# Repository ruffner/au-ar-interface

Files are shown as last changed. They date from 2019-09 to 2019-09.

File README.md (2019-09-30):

# au-ar-interface
machine vision and hdmi interface for alchitry labs au artix 7 fpga

## layer stackup
I use pcbway and this is the layer configuration from them that this board is based on. 
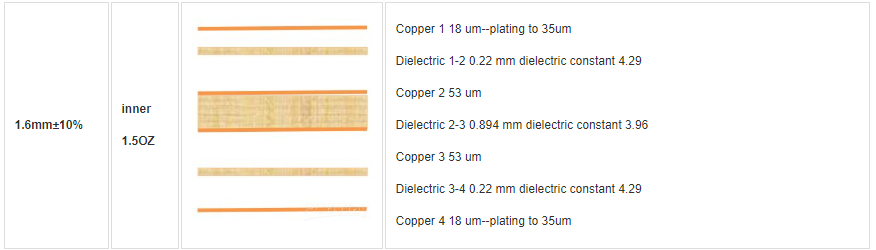
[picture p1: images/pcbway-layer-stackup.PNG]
pcbway 1.6mm 4 layer 1.5oz inner stackup Layer Stackup


## hdmi impedance calcluation and design considerations
Saturn PCB Toolkit was used to calculate the necessary trace widths and spacing to achieve the 100 ohm differential impedance target of the HDMI specification.
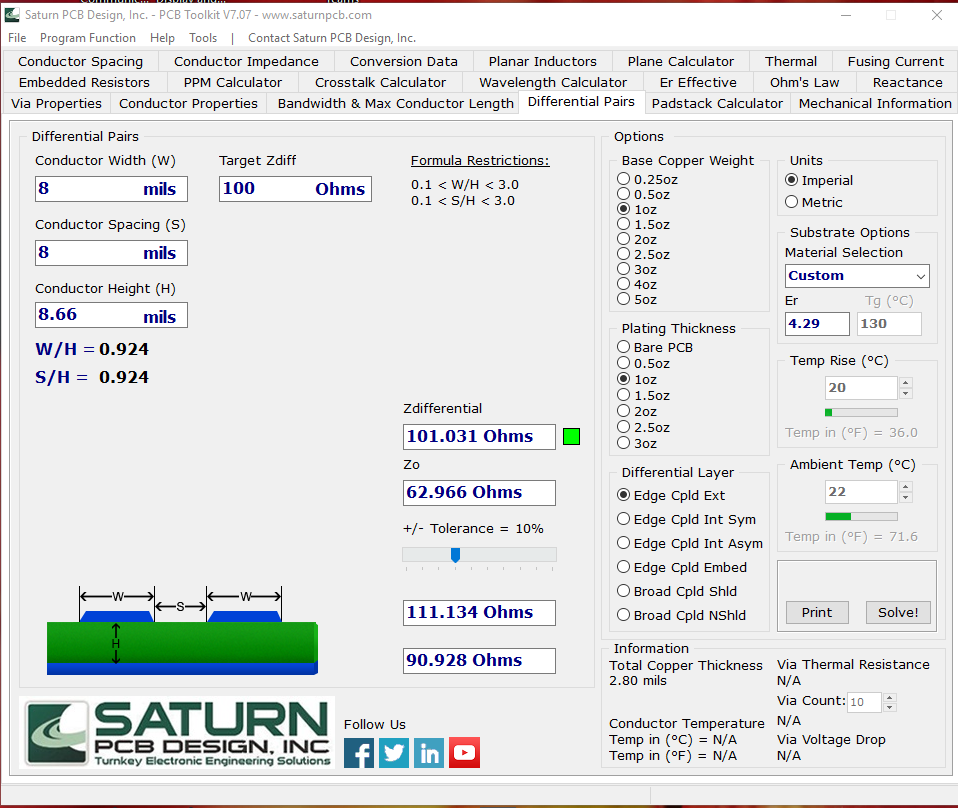
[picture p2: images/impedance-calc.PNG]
pcbway 1.6mm 4 layer 1.5oz inner stackup Impedance and trace calculations


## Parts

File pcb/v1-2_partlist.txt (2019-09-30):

Partlist

Exported from au-ar.sch at 9/30/2019 1:22 PM

EAGLE Version 9.5.1 Copyright (c) 1988-2019 Autodesk, Inc.

Assembly variant: 

Part        Value              Device             Package                Library            Sheet

1           LINE_1             TPTP16R            TP16R                  testpad            4
2           LINE_2             TPTP16R            TP16R                  testpad            4
3           LINE_3             TPTP16R            TP16R                  testpad            4
4           LINE_1             TPTP16R            TP16R                  testpad            4
B1          ALCHITRY_ELEMENTNT ALCHITRY_ELEMENTNT ELEMENT_NO_TOP         alchitry_elements  1
C1          0.1uF              C-USC0603          C0603                  rcl                6
C2          0.1uF              C-USC0603          C0603                  rcl                3
C3          0.1uF              C-USC0603          C0603                  rcl                3
C4          0.1uF              C-USC0603          C0603                  rcl                3
C5          0.1uF              C-USC0603          C0603                  rcl                3
C9          0.1uF              C-USC0603          C0603                  rcl                2
C10         0.1uF              C-USC0603          C0603                  rcl                2
C11         0.1uF              C-USC0603          C0603                  rcl                2
C12         0.1uF              C-USC0603          C0603                  rcl                2
CAMERA1     S6B-PH-K-S(LF)(SN) S6B-PH-K-S(LF)(SN) JST_S6B-PH-K-S(LF)(SN) S6B-PH-K-S_LF__SN_ 4
CAMERA2     S6B-PH-K-S(LF)(SN) S6B-PH-K-S(LF)(SN) JST_S6B-PH-K-S(LF)(SN) S6B-PH-K-S_LF__SN_ 4
FLASH       0532610571         0532610571         PICOBLADE53261-0571    volks73-Molex      5
HDMI_IN/OUT 10029449-001RLF    10029449-001RLF    FCI_10029449-001RLF    10029449-001RLF    2
HDMI_OUT    10029449-001RLF    10029449-001RLF    FCI_10029449-001RLF    10029449-001RLF    2
LINE_1_1    TPTP16R            TPTP16R            TP16R                  testpad            4
LINE_1_2    TPTP16R            TPTP16R            TP16R                  testpad            4
LINE_1_3    TPTP16R            TPTP16R            TP16R                  testpad            4
LINE_1_4    TPTP16R            TPTP16R            TP16R                  testpad            4
R1          DNP                R-US_R0603         R0603                  rcl                4
R2          DNP                R-US_R0603         R0603                  rcl                4
R3          DNP                R-US_R0603         R0603                  rcl                4
R4          DNP                R-US_R0603         R0603                  rcl                4
R5          47k                R-US_R0603         R0603                  rcl                5
R6          3k                 R-US_R0603         R0603                  rcl                6
R7          DNP                R-US_R0603         R0603                  rcl                4
R8          DNP                R-US_R0603         R0603                  rcl                4
R9          DNP                R-US_R0603         R0603                  rcl                4
R10         DNP                R-US_R0603         R0603                  rcl                4
R11         DNP                R-US_R0603         R0603                  rcl                4
R12         DNP                R-US_R0603         R0603                  rcl                4
R13         DNP                R-US_R0603         R0603                  rcl                4
R14         DNP                R-US_R0603         R0603                  rcl                4
R15         DNP                R-US_R0603         R0603                  rcl                4
R16         DNP                R-US_R0603         R0603                  rcl                4
R17         DNP                R-US_R0603         R0603                  rcl                4
R18         DNP                R-US_R0603         R0603                  rcl                4
R19         DNP                R-US_R0603         R0603                  rcl                4
R20         DNP                R-US_R0603         R0603                  rcl                4
R21         DNP                R-US_R0603         R0603                  rcl                4
R22         DNP                R-US_R0603         R0603                  rcl                4
R23         DNP                R-US_R0603         R0603                  rcl                4
R24         DNP                R-US_R0603         R0603                  rcl                4
R25         DNP                R-US_R0603         R0603                  rcl                4
R26         DNP                R-US_R0603         R0603                  rcl                4
R27         3k                 R-US_R0603         R0603                  rcl                6
R28         2k                 R-US_R0603         R0603                  rcl                2
R29         10k                R-US_R0603         R0603                  rcl                2
R30         10k                R-US_R0603         R0603                  rcl                2
SI514       SI514              SI514              XTAL-6PIN              lupa300-components 6
SJ1                            SJ                 SJ                     jumper             2
TP_GND      TPTP16R            TPTP16R            TP16R                  testpad            4
U$1         W25Q80DVSNIG       W25Q80DVSNIG       SOIC8                  TDP12S521          5
U1          TPD12S016PWR       TPD12S016PWR       PW24                   lupa300-components 3
U2          TPD12S016PWR       TPD12S016PWR       PW24                   lupa300-components 3

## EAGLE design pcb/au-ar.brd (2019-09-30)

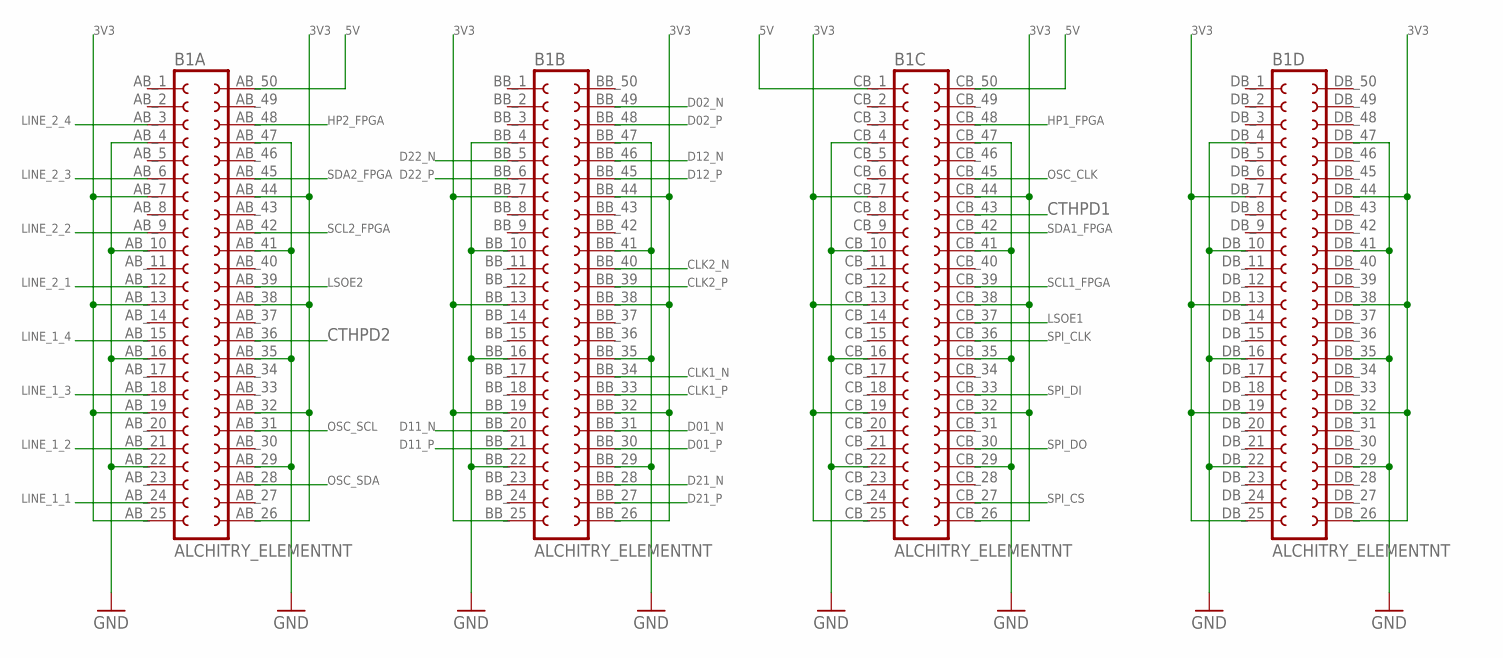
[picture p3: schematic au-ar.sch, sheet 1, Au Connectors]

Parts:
B1: ALCHITRY_ELEMENTNT; ELEMENT_NO_TOP

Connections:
3V3: B1.AB_7 (7), B1.AB_13 (13), B1.AB_19 (19), B1.AB_25 (25), B1.AB_26 (26), B1.AB_32 (32), B1.AB_38 (38), B1.AB_44 (44), B1.BB_7 (7), B1.BB_13 (13), B1.BB_19 (19), B1.BB_25 (25), B1.BB_26 (26), B1.BB_32 (32), B1.BB_38 (38), B1.BB_44 (44), B1.CB_7 (7), B1.CB_13 (13), B1.CB_19 (19), B1.CB_25 (25), B1.CB_26 (26), B1.CB_32 (32), B1.CB_38 (38), B1.CB_44 (44), B1.DB_7 (7), B1.DB_13 (13), B1.DB_19 (19), B1.DB_25 (25), B1.DB_26 (26), B1.DB_32 (32), B1.DB_38 (38), B1.DB_44 (44); also elsewhere on the board
5V: B1.AB_50 (50), B1.CB_1 (1), B1.CB_50 (50); also elsewhere on the board
CLK1_N: B1.BB_34 (34); also elsewhere on the board
CLK1_P: B1.BB_33 (33); also elsewhere on the board
CLK2_N: B1.BB_40 (40); also elsewhere on the board
CLK2_P: B1.BB_39 (39); also elsewhere on the board
CTHPD1: B1.CB_43 (43); also elsewhere on the board
CTHPD2: B1.AB_36 (36); also elsewhere on the board
D01_N: B1.BB_31 (31); also elsewhere on the board
D01_P: B1.BB_30 (30); also elsewhere on the board
D02_N: B1.BB_49 (49); also elsewhere on the board
D02_P: B1.BB_48 (48); also elsewhere on the board
D11_N: B1.BB_20 (20); also elsewhere on the board
D11_P: B1.BB_21 (21); also elsewhere on the board
D12_N: B1.BB_46 (46); also elsewhere on the board
D12_P: B1.BB_45 (45); also elsewhere on the board
D21_N: B1.BB_28 (28); also elsewhere on the board
D21_P: B1.BB_27 (27); also elsewhere on the board
D22_N: B1.BB_5 (5); also elsewhere on the board
D22_P: B1.BB_6 (6); also elsewhere on the board
GND: B1.AB_4 (4), B1.AB_10 (10), B1.AB_16 (16), B1.AB_22 (22), B1.AB_29 (29), B1.AB_35 (35), B1.AB_41 (41), B1.AB_47 (47), B1.BB_4 (4), B1.BB_10 (10), B1.BB_16 (16), B1.BB_22 (22), B1.BB_29 (29), B1.BB_35 (35), B1.BB_41 (41), B1.BB_47 (47), B1.CB_4 (4), B1.CB_10 (10), B1.CB_16 (16), B1.CB_22 (22), B1.CB_29 (29), B1.CB_35 (35), B1.CB_41 (41), B1.CB_47 (47), B1.DB_4 (4), B1.DB_10 (10), B1.DB_16 (16), B1.DB_22 (22), B1.DB_29 (29), B1.DB_35 (35), B1.DB_41 (41), B1.DB_47 (47); also elsewhere on the board
HP1_FPGA: B1.CB_48 (48); also elsewhere on the board
HP2_FPGA: B1.AB_48 (48); also elsewhere on the board
LINE_1_1: B1.AB_24 (24); also elsewhere on the board
LINE_1_2: B1.AB_21 (21); also elsewhere on the board
LINE_1_3: B1.AB_18 (18); also elsewhere on the board
LINE_1_4: B1.AB_15 (15); also elsewhere on the board
LINE_2_1: B1.AB_12 (12); also elsewhere on the board
LINE_2_2: B1.AB_9 (9); also elsewhere on the board
LINE_2_3: B1.AB_6 (6); also elsewhere on the board
LINE_2_4: B1.AB_3 (3); also elsewhere on the board
LSOE1: B1.CB_37 (37); also elsewhere on the board
LSOE2: B1.AB_39 (39); also elsewhere on the board
OSC_CLK: B1.CB_45 (45); also elsewhere on the board
OSC_SCL: B1.AB_31 (31); also elsewhere on the board
OSC_SDA: B1.AB_28 (28); also elsewhere on the board
SCL1_FPGA: B1.CB_39 (39); also elsewhere on the board
SCL2_FPGA: B1.AB_42 (42); also elsewhere on the board
SDA1_FPGA: B1.CB_42 (42); also elsewhere on the board
SDA2_FPGA: B1.AB_45 (45); also elsewhere on the board
SPI_CLK: B1.CB_36 (36); also elsewhere on the board
SPI_CS: B1.CB_27 (27); also elsewhere on the board
SPI_DI: B1.CB_33 (33); also elsewhere on the board
SPI_DO: B1.CB_30 (30); also elsewhere on the board

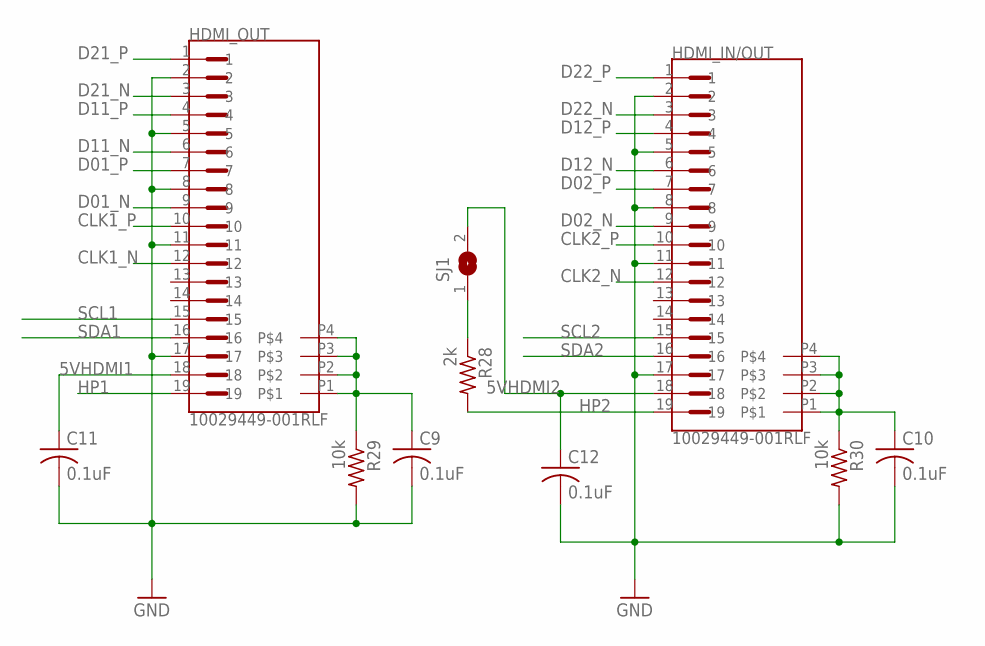
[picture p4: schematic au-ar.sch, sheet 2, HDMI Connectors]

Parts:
C9, C10, C11, C12: 0.1uF; C0603
HDMI_IN/OUT: 10029449-001RLF; FCI_10029449-001RLF
HDMI_OUT: 10029449-001RLF; FCI_10029449-001RLF
R28: 2k; R0603
R29, R30: 10k; R0603
SJ1: SJ

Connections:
5VHDMI1: C11.1, HDMI_OUT.18; also elsewhere on the board
5VHDMI2: C12.1, HDMI_IN/OUT.18, SJ1.2; also elsewhere on the board
CLK1_N: HDMI_OUT.12; also elsewhere on the board
CLK1_P: HDMI_OUT.10; also elsewhere on the board
CLK2_N: HDMI_IN/OUT.12; also elsewhere on the board
CLK2_P: HDMI_IN/OUT.10; also elsewhere on the board
D01_N: HDMI_OUT.9; also elsewhere on the board
D01_P: HDMI_OUT.7; also elsewhere on the board
D02_N: HDMI_IN/OUT.9; also elsewhere on the board
D02_P: HDMI_IN/OUT.7; also elsewhere on the board
D11_N: HDMI_OUT.6; also elsewhere on the board
D11_P: HDMI_OUT.4; also elsewhere on the board
D12_N: HDMI_IN/OUT.6; also elsewhere on the board
D12_P: HDMI_IN/OUT.4; also elsewhere on the board
D21_N: HDMI_OUT.3; also elsewhere on the board
D21_P: HDMI_OUT.1; also elsewhere on the board
D22_N: HDMI_IN/OUT.3; also elsewhere on the board
D22_P: HDMI_IN/OUT.1; also elsewhere on the board
GND: C9.2, C10.2, C11.2, C12.2, HDMI_IN/OUT.2, HDMI_IN/OUT.5, HDMI_IN/OUT.8, HDMI_IN/OUT.11, HDMI_IN/OUT.17, HDMI_OUT.2, HDMI_OUT.5, HDMI_OUT.8, HDMI_OUT.11, HDMI_OUT.17, R29.2, R30.2; also elsewhere on the board
HP1: HDMI_OUT.19; also elsewhere on the board
HP2: HDMI_IN/OUT.19, R28.2; also elsewhere on the board
unnamed: R28.1, SJ1.1
unnamed: C9.1, HDMI_OUT.P1, HDMI_OUT.P2, HDMI_OUT.P3, HDMI_OUT.P4, R29.1
unnamed: C10.1, HDMI_IN/OUT.P1, HDMI_IN/OUT.P2, HDMI_IN/OUT.P3, HDMI_IN/OUT.P4, R30.1
SCL1: HDMI_OUT.15; also elsewhere on the board
SCL2: HDMI_IN/OUT.15; also elsewhere on the board
SDA1: HDMI_OUT.16; also elsewhere on the board
SDA2: HDMI_IN/OUT.16; also elsewhere on the board

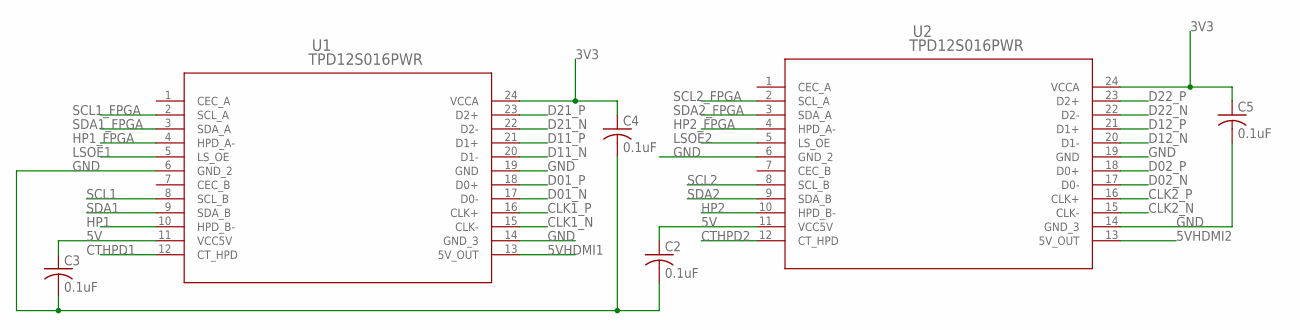
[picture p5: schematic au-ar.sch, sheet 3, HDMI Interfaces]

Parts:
C2, C3, C4, C5: 0.1uF; C0603
U1, U2: TPD12S016PWR; PW24

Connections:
3V3: C4.1, C5.1, U1.24 (VCCA), U2.24 (VCCA); also elsewhere on the board
5V: C2.1, C3.1, U1.11 (VCC5V), U2.11 (VCC5V); also elsewhere on the board
5VHDMI1: U1.13 (5V_OUT); also elsewhere on the board
5VHDMI2: U2.13 (5V_OUT); also elsewhere on the board
CLK1_N: U1.15 (CLK-); also elsewhere on the board
CLK1_P: U1.16 (CLK+); also elsewhere on the board
CLK2_N: U2.15 (CLK-); also elsewhere on the board
CLK2_P: U2.16 (CLK+); also elsewhere on the board
CTHPD1: U1.12 (CT_HPD); also elsewhere on the board
CTHPD2: U2.12 (CT_HPD); also elsewhere on the board
D01_N: U1.17 (D0-); also elsewhere on the board
D01_P: U1.18 (D0+); also elsewhere on the board
D02_N: U2.17 (D0-); also elsewhere on the board
D02_P: U2.18 (D0+); also elsewhere on the board
D11_N: U1.20 (D1-); also elsewhere on the board
D11_P: U1.21 (D1+); also elsewhere on the board
D12_N: U2.20 (D1-); also elsewhere on the board
D12_P: U2.21 (D1+); also elsewhere on the board
D21_N: U1.22 (D2-); also elsewhere on the board
D21_P: U1.23 (D2+); also elsewhere on the board
D22_N: U2.22 (D2-); also elsewhere on the board
D22_P: U2.23 (D2+); also elsewhere on the board
GND: C2.2, C3.2, C4.2, C5.2, U1.6 (GND_2), U1.14 (GND_3), U1.19 (GND), U2.6 (GND_2), U2.14 (GND_3), U2.19 (GND); also elsewhere on the board
HP1: U1.10 (HPD_B-); also elsewhere on the board
HP1_FPGA: U1.4 (HPD_A-); also elsewhere on the board
HP2: U2.10 (HPD_B-); also elsewhere on the board
HP2_FPGA: U2.4 (HPD_A-); also elsewhere on the board
LSOE1: U1.5 (LS_OE); also elsewhere on the board
LSOE2: U2.5 (LS_OE); also elsewhere on the board
SCL1: U1.8 (SCL_B); also elsewhere on the board
SCL1_FPGA: U1.2 (SCL_A); also elsewhere on the board
SCL2: U2.8 (SCL_B); also elsewhere on the board
SCL2_FPGA: U2.2 (SCL_A); also elsewhere on the board
SDA1: U1.9 (SDA_B); also elsewhere on the board
SDA1_FPGA: U1.3 (SDA_A); also elsewhere on the board
SDA2: U2.9 (SDA_B); also elsewhere on the board
SDA2_FPGA: U2.3 (SDA_A); also elsewhere on the board

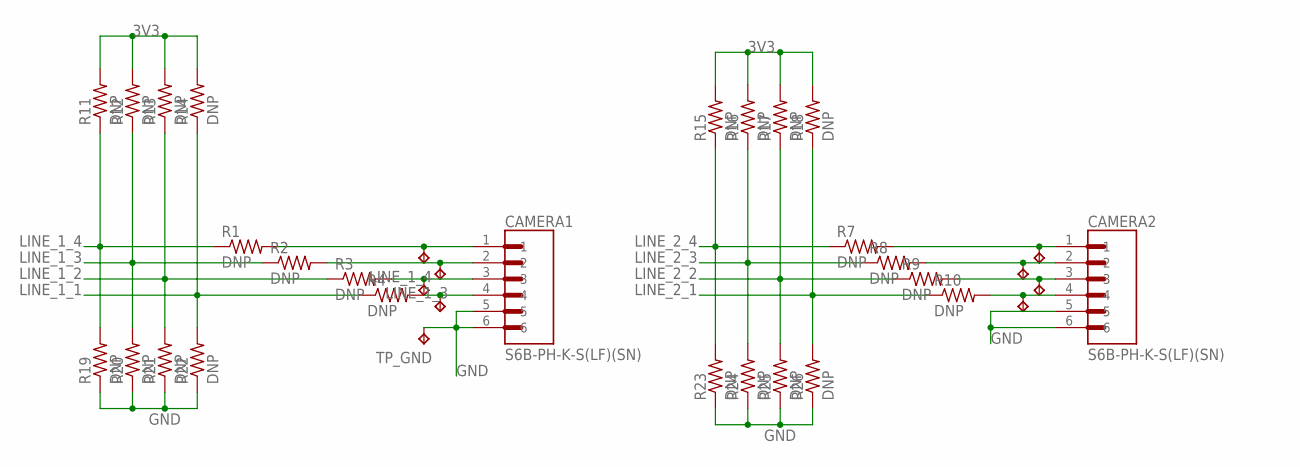
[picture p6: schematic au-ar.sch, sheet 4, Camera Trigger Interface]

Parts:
1, 4: LINE_1; TP16R
2: LINE_2; TP16R
3: LINE_3; TP16R
CAMERA1, CAMERA2: S6B-PH-K-S(LF)(SN); JST_S6B-PH-K-S(LF)(SN)
LINE_1_1, LINE_1_2, LINE_1_3, LINE_1_4: TPTP16R; TP16R
R1, R2, R3, R4, R7, R8, R9, R10, R11, R12, R13, R14, R15, R16, R17, R18, R19, R20, R21, R22, R23, R24, R25, R26: DNP; R0603
TP_GND: TPTP16R; TP16R

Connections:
3V3: R11.2, R12.2, R13.2, R14.2, R15.2, R16.2, R17.2, R18.2; also elsewhere on the board
GND: CAMERA1.5, CAMERA1.6, CAMERA2.5, CAMERA2.6, R19.1, R20.1, R21.1, R22.1, R23.1, R24.1, R25.1, R26.1, TP_GND.TP; also elsewhere on the board
LINE_1_1: R4.1, R14.1, R22.2; also elsewhere on the board
LINE_1_2: R3.1, R13.1, R21.2; also elsewhere on the board
LINE_1_3: R2.1, R12.1, R20.2; also elsewhere on the board
LINE_1_4: R1.1, R11.1, R19.2; also elsewhere on the board
LINE_2_1: R10.1, R18.1, R26.2; also elsewhere on the board
LINE_2_2: R9.1, R17.1, R25.2; also elsewhere on the board
LINE_2_3: R8.1, R16.1, R24.2; also elsewhere on the board
LINE_2_4: R7.1, R15.1, R23.2; also elsewhere on the board
unnamed: 4.TP, CAMERA2.1, R7.2
unnamed: 3.TP, CAMERA2.2, R8.2
unnamed: 2.TP, CAMERA2.3, R9.2
unnamed: 1.TP, CAMERA2.4, R10.2
unnamed: CAMERA1.1, LINE_1_4.TP, R1.2
unnamed: CAMERA1.2, LINE_1_3.TP, R2.2
unnamed: CAMERA1.3, LINE_1_2.TP, R3.2
unnamed: CAMERA1.4, LINE_1_1.TP, R4.2

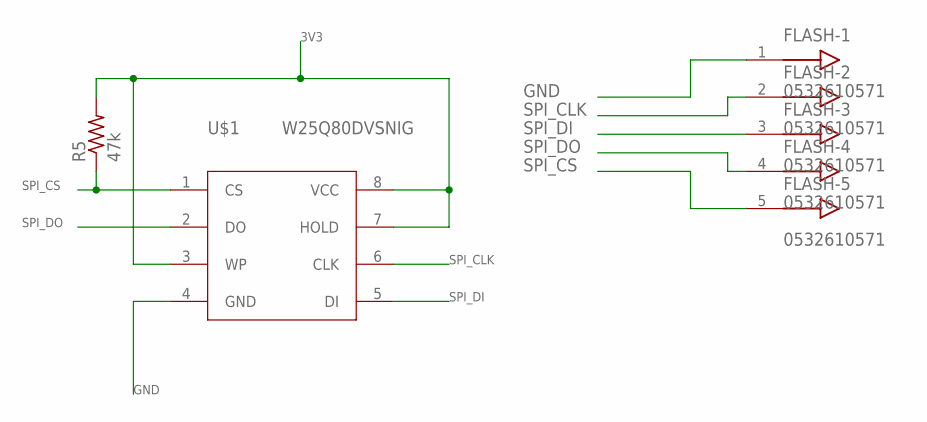
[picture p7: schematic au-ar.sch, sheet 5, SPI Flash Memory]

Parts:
FLASH: 0532610571; PICOBLADE53261-0571
R5: 47k; R0603
U$1: W25Q80DVSNIG; SOIC8

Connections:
3V3: R5.2, U$1.3 (WP), U$1.7 (HOLD), U$1.8 (VCC); also elsewhere on the board
GND: FLASH.1, U$1.4 (GND); also elsewhere on the board
SPI_CLK: FLASH.2, U$1.6 (CLK); also elsewhere on the board
SPI_CS: FLASH.5, R5.1, U$1.1 (CS); also elsewhere on the board
SPI_DI: FLASH.3, U$1.5 (DI); also elsewhere on the board
SPI_DO: FLASH.4, U$1.2 (DO); also elsewhere on the board

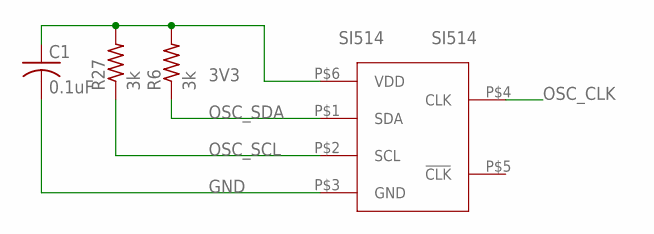
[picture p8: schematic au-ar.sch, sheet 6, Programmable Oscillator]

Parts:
C1: 0.1uF; C0603
R6, R27: 3k; R0603
SI514: SI514; XTAL-6PIN

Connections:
3V3: C1.1, R6.2, R27.2, SI514.P$6 (VDD); also elsewhere on the board
GND: C1.2, SI514.P$3 (GND); also elsewhere on the board
OSC_CLK: SI514.P$4 (CLK); also elsewhere on the board
OSC_SCL: R27.1, SI514.P$2 (SCL); also elsewhere on the board
OSC_SDA: R6.1, SI514.P$1 (SDA); also elsewhere on the board

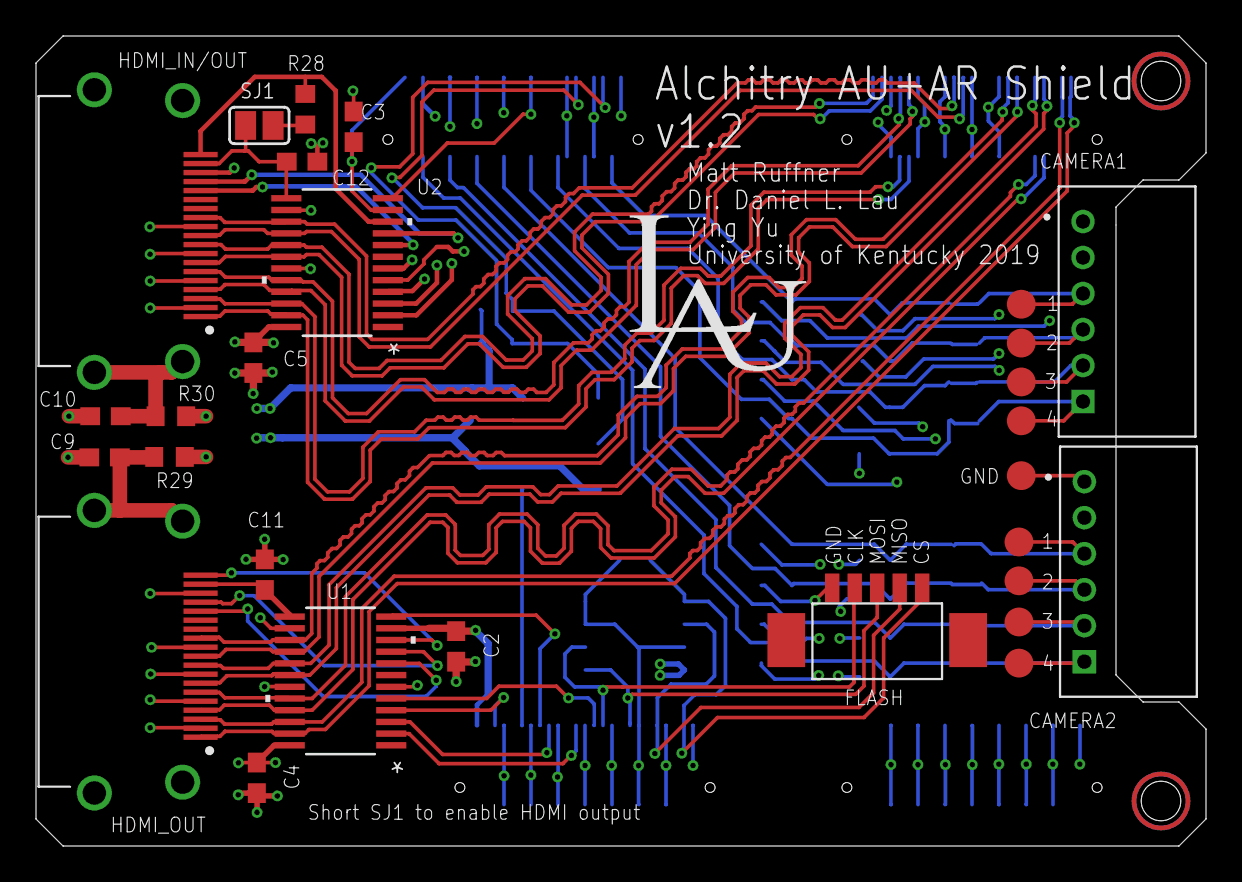
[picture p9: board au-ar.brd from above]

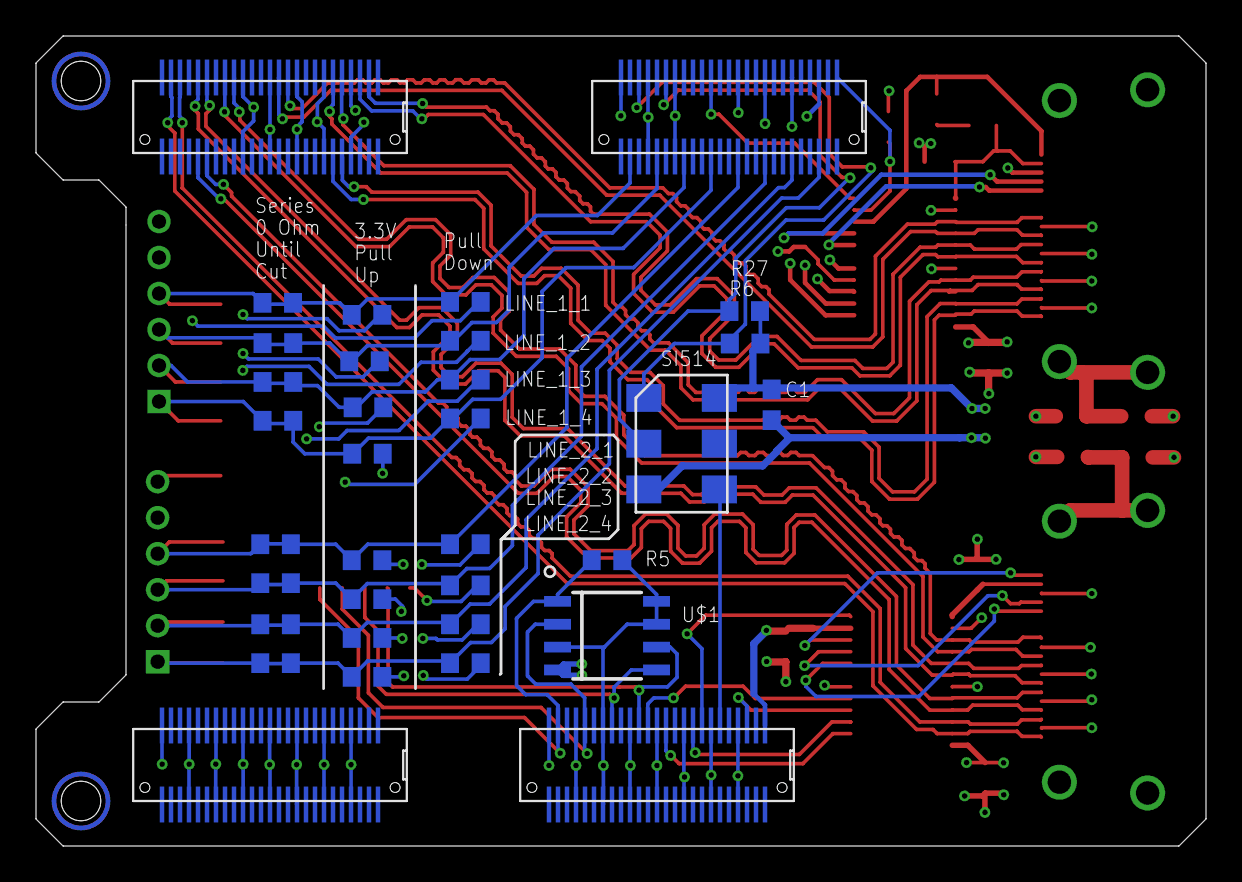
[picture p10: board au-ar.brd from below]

Board: 4 copper layers, 65.0 x 45.0 mm, 59 parts (30 on the bottom side), 63 nets.

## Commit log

2019-04-10 started au-ar layout
    [au-ar.brd, au-ar.sch]
2019-04-11 placed signal config resistors for camera trigger interface. relocated hdmi ports
    [au-ar.brd]
2019-04-12 rearranged hdmi ports. removed end mounting holes to make room for dual ports on the end. added footprint for spi flash and added to schematic.
    [au-ar.brd, au-ar.sch]
2019-04-15 added remaining connections in schematic for spi flash and hdmi ddc bus
    [au-ar.brd, au-ar.sch]
2019-04-15 started routing hdmi tmds signals. had to make min hole size .2mm
    [au-ar.brd, au-ar.sch]
2019-04-15 more routing
    [au-ar.brd]
2019-04-18 reorganized hdmi pins, hdmi routing almost done
    [au-ar.brd, au-ar.sch]
2019-04-22 routed hdmi, need to route low speed signals
    [au-ar.brd, au-ar.sch]
2019-04-24 added more routing
    [au-ar.brd]
2019-04-29 added final edits for v1 order and pcbway gerbers
    [au-ar.brd, au-ar.sch]
2019-05-10 added external oscillator
    [au-ar.brd, au-ar.sch]
2019-05-31 started rerouting with new esd protection chips
    [au-ar.brd, au-ar.sch]
2019-05-31 almost done routing
    [au-ar.brd, au-ar.sch]
2019-06-04 need to add mosfet and order
    [au-ar.brd, au-ar.sch]
2019-07-05 added most recent gerbers
2019-07-05 updated newest gerbers
2019-08-20 retuned hdmi trace lengths, added ground pour and cutouts under hdmi connectors
    [au-ar.brd, au-ar.sch]
2019-08-20 added partslist and solder jumper for hdmi input, labeled hdmi input and output added up to date gerbers.
    [au-ar.brd, au-ar.sch]
2019-09-30 hdmi ground vias moved
    [au-ar.brd, au-ar.sch]
2019-09-30 v1.2 silk edits
    [au-ar.brd, au-ar.sch]
2019-09-30 final mods to v1.2 pcb and addition of v1.2 gerbers
    [au-ar.brd]

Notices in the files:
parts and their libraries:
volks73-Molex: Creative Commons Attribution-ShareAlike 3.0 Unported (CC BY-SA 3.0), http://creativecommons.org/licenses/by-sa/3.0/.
